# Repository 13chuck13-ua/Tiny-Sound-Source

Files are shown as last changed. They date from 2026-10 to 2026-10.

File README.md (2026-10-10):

# Tiny Sound Source
Tiny Sound Source is an 8-bit LPT DAC compatible with the Covox Speech Thing and Disney Sound Source. It is built around an AVR ATtiny2313 microcontroller and uses a minimal number of additional components.

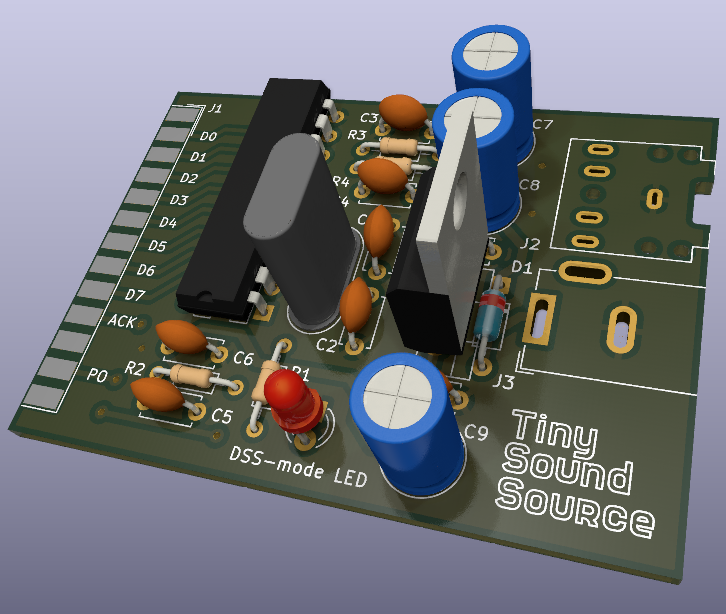
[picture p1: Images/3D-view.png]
Tiny Sound Source


## Key Features:
 - Automatic switching between Covox and DSS modes, with LED indication.
 - Covox mode: flexible sampling rate determined by the host and protection against read errors.
 - DSS mode: doubled output sampling rate (14 kHz) with simple linear interpolation.
 - An additional low-pass filter, automatically enabled by software in DSS mode.
 - Audio output via the built-in PWM at 62.5 kHz.
 - Compatibility with the FTL Sound Adapter.

## Content
 - The **AVR-GCC** directory contains code for the microcontroller.
 - The **KiCad** directory contains the schematic, PCB layout, and Gerber files.

## Tested in the following games:
| Name | Sound | Autodetect  |
| :--- | :---: | :---: |
| Alone in the Dark | 🟢OK | 🟢OK |
| Another World | 🟢OK | ⚪N/A |
| Dungeon Master | 🟢OK | 🟢OK |
| Fast Doom | 🟢OK | ⚪N/A |
| Hocus Pocus | 🟢OK | 🔴Not working|
| King's Quest VI | 🟢OK | 🟢OK |
| Prince of Persia v1.3 | 🟢OK | ⚪N/A |
| Prince of Persia 2 | 🟢OK | ⚪N/A |
| Rocketeer | 🟢OK | ⚪N/A |
| Space Quest V | 🟢OK | ⚪N/A |
| Wolfenstein 3D | 🟢OK | 🟢OK |

**A quick word about Hocus Pocus**.
This game behaves strangely during the DSS auto-detection process. For the device to work correctly, a buffer with TTL input levels needs to be added to the microcontroller's INT0 and INT1 inputs. However, the Tiny Sound Source is, first and foremost, a simple device. I refuse to add a separate chip just for auto-detection in a single game.
To force the use of the Disney Sound Source in Hocus Pocus, use the following command-line switches:
 - **-ss1** for LPT at 0x3BC
 - **-ss2** for LPT at 0x378
 - **-ss3** for LPT at 0x278

## License
The project is distributed under the **GPLv3** license. The license text is in the **GPLv3.txt** file.

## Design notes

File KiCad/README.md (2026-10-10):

# Tiny Sound Source - KiCad files.
Schematic, PCB layout, and Gerber files.

The circuit has been tested and works correctly on:
- **IBM PS/1 model 2121** 80386SX-20MHz
- **CMP MIG-32 laptop** 80286-12MHz

## Schematic
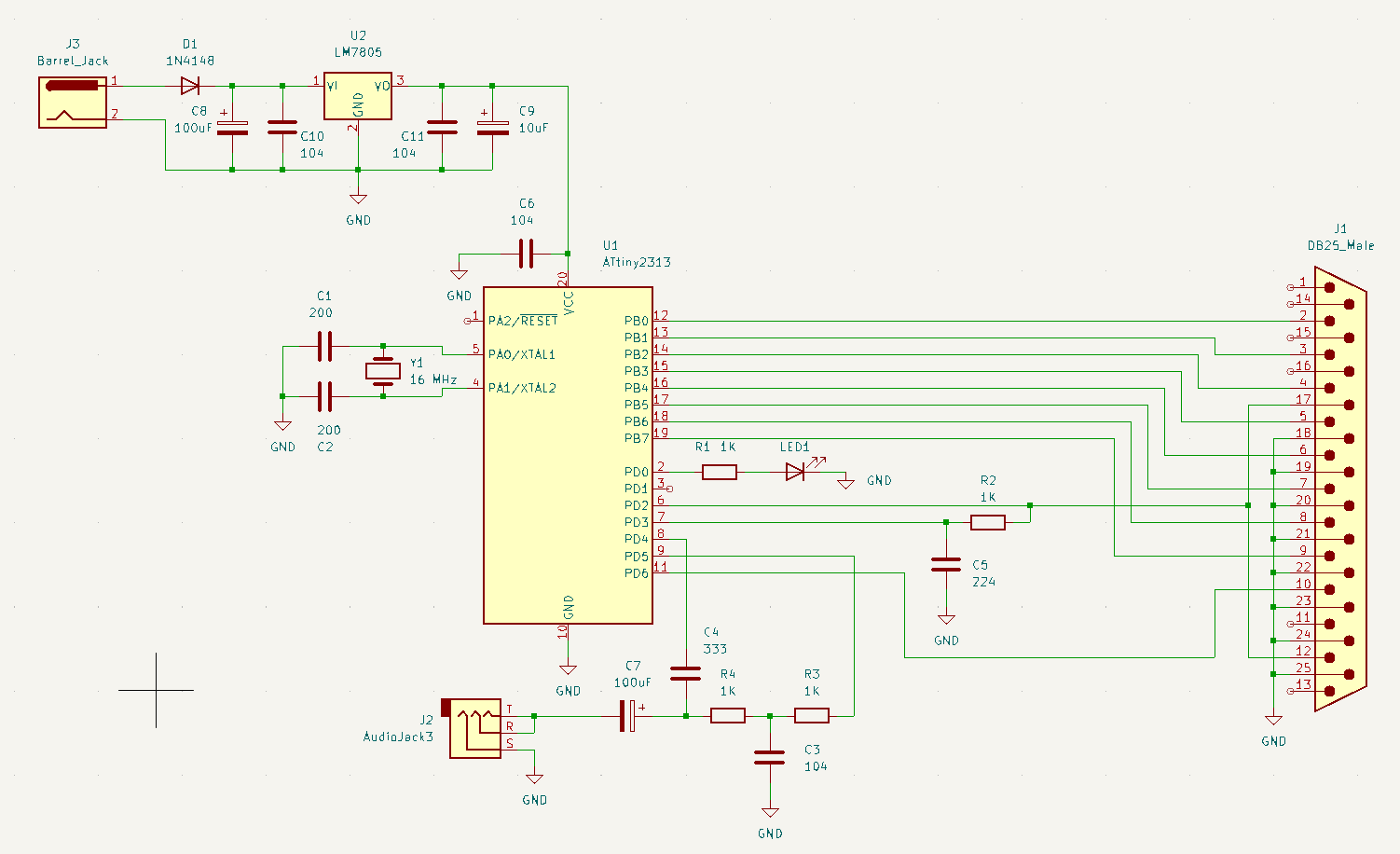
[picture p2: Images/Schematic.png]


 - **R2** та **C5** separate the long SELECT (INT1) signal from the short STROBE (INT0) pulses. Component values may need to be adjusted.
 - **R3** and **C3** are the main PWM output filter.
 - **R4** and **C4** are an additional filter for DSS mode. If you do not need this filter, replace **R4** with a jumper and do not install **C4**.
 - "Compatibility with the FTL Sound Adapter" is simply a jumper wire between pins 12 and 17 of the LPT connector.

## PCB layout
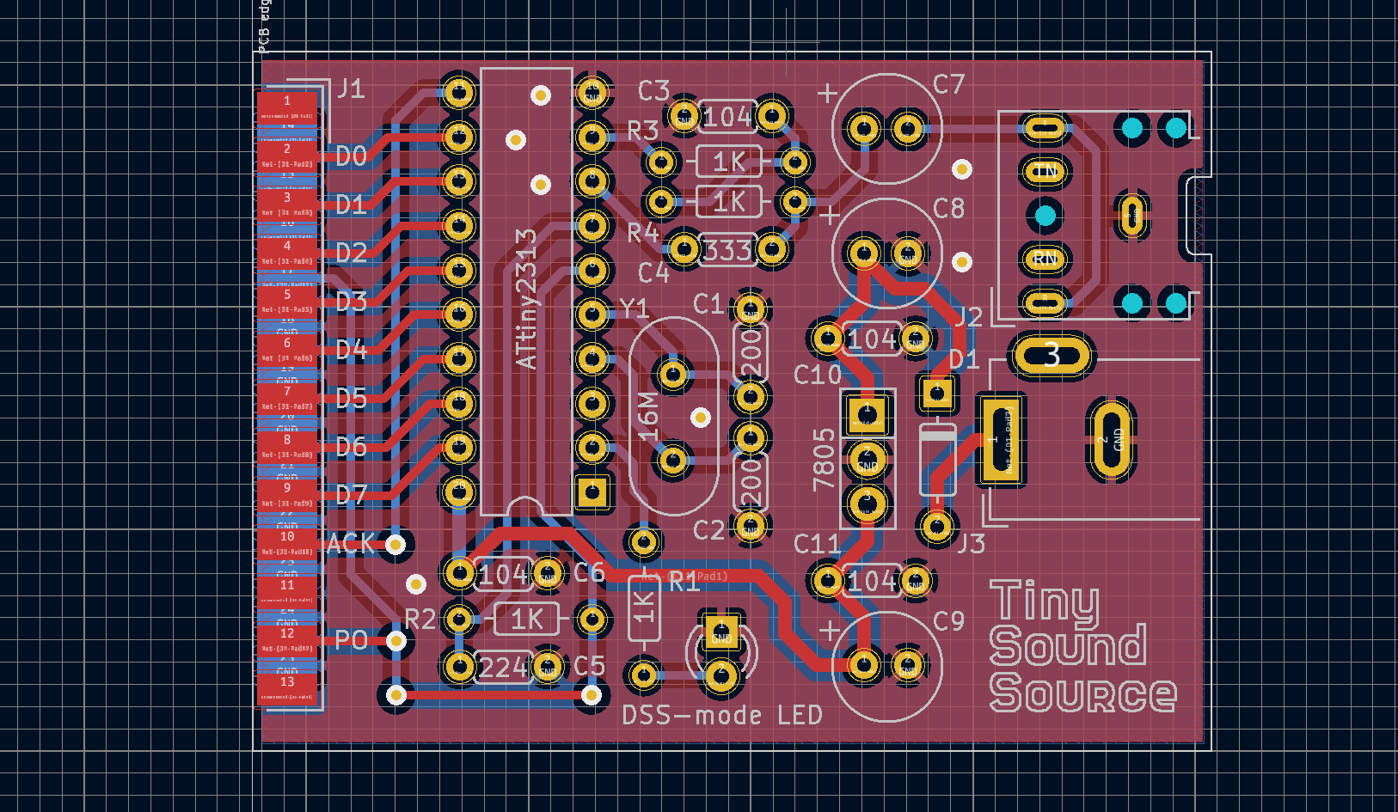
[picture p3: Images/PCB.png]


Ready-to-use Gerber files are located in the Gerber subdirectory.
If you wish to make changes and generate your own Gerber files, I recommend using the User.Drawings layer as F.Silkscreen.

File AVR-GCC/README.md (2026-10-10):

# Tiny Sound Source - GCC code
AVR-GCC firmware for Tiny Sound Source.

## Device:
 - ATtiny2313

## Files:
 - main.c — source code.
 - Makefile — build instructions.
 - tss.hex — compiled firmware image.

## Building:
 - Requires **AVR-GCC** and **GNU Make**.
 - Run make to build the firmware.

## Flashing:
 - Use a compatible AVR programmer and the appropriate flashing utility to write tss.hex to microcontroller.
 - FUSES: LFUSE - **0xDF** HFUSE - **0xD1**

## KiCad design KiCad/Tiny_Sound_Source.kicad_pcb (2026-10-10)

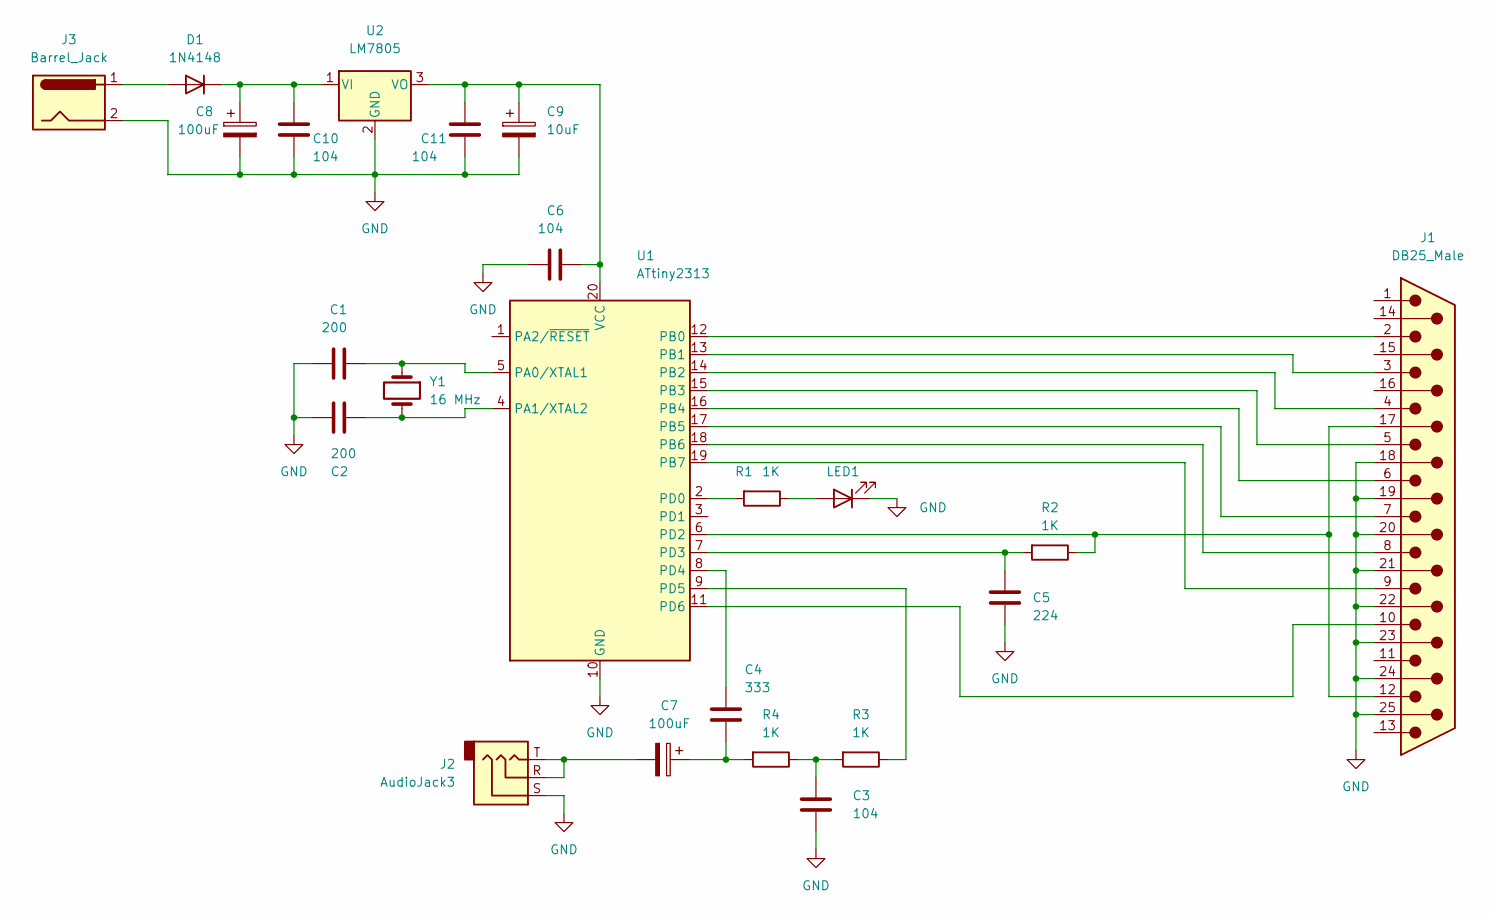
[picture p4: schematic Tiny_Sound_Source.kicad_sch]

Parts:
C1, C2: 200; C_Disc_D4.7mm_W2.5mm_P5.00mm
C3, C6, C10, C11: 104; C_Disc_D4.7mm_W2.5mm_P5.00mm
C4: 333; C_Disc_D4.7mm_W2.5mm_P5.00mm
C5: 224; C_Disc_D4.7mm_W2.5mm_P5.00mm
C7, C8: 100uF; C_Radial_D6.3mm_H11.0mm_P2.50mm
C9: 10uF; C_Radial_D6.3mm_H11.0mm_P2.50mm
D1: 1N4148; D_DO-35_SOD27_P7.62mm_Horizontal
J1: DB25_Male; DSUB-25_Male_EdgeMount_P2.77mm
J2: AudioJack3; Jack_3.5mm_CUI_SJ1-3525N_Horizontal
J3: Barrel_Jack; BarrelJack_GCT_DCJ200-10-A_Horizontal
LED1: DSS-mode LED; LED_D3.0mm
R1, R2, R3, R4: 1K; R_Axial_DIN0204_L3.6mm_D1.6mm_P7.62mm_Horizontal
U1: ATtiny2313; DIP-20_W7.62mm
U2: LM7805; TO-220-3_Vertical
Y1: 16 MHz; Crystal_HC18-U_Vertical

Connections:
GND: C1.1, C2.2, C3.2, C5.2, C6.2, C8.2, C9.2, C10.2, C11.2, J1.18, J1.19, J1.20, J1.21, J1.22, J1.23, J1.24, J1.25, J2.S, J3.2, LED1.1 (K), U1.10 (GND), U2.2 (GND)
unnamed: C1.2, U1.5 (PA0/XTAL1), Y1.1
unnamed: C2.1, U1.4 (PA1/XTAL2), Y1.2
unnamed: C3.1, R3.2, R4.1
unnamed: C4.1, U1.8 (PD4)
unnamed: C4.2, C7.1, R4.2
unnamed: C5.1, R2.2, U1.7 (PD3)
unnamed: C7.2, J2.R, J2.T
unnamed: C8.1, C10.1, D1.1 (K), U2.1 (VI)
unnamed: C6.1, C9.1, C11.1, U1.20 (VCC), U2.3 (VO)
unnamed: D1.2 (A), J3.1
unnamed: J1.2, U1.12 (PB0)
unnamed: J1.3, U1.13 (PB1)
unnamed: J1.4, U1.14 (PB2)
unnamed: J1.5, U1.15 (PB3)
unnamed: J1.6, U1.16 (PB4)
unnamed: J1.7, U1.17 (PB5)
unnamed: J1.8, U1.18 (PB6)
unnamed: J1.9, U1.19 (PB7)
unnamed: J1.10, U1.11 (PD6)
unnamed: J1.12, J1.17, R2.1, U1.6 (PD2)
unnamed: LED1.2 (A), R1.1
unnamed: R1.2, U1.2 (PD0)
unnamed: R3.1, U1.9 (PD5)

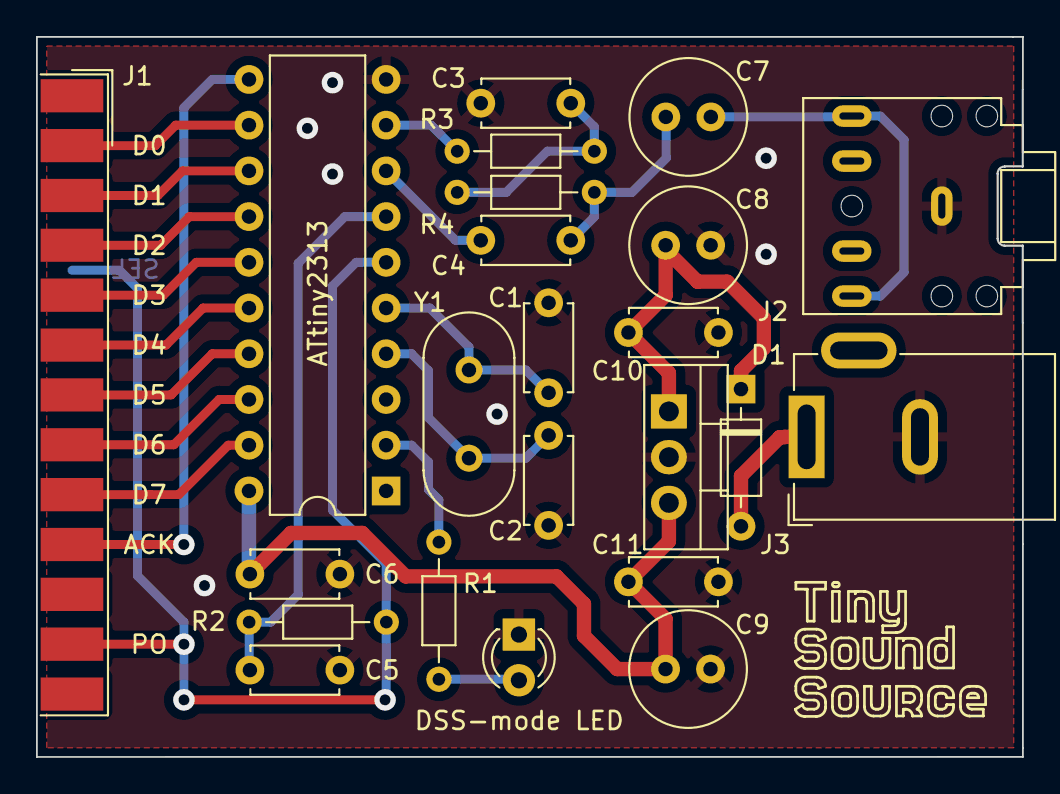
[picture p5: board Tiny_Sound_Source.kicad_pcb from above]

Board: 2 copper layers, 54.8 x 40.0 mm, 23 parts (0 on the bottom side), 24 nets.

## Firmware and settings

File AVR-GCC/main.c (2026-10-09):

/* ============================================================================
 *   _______             ____                  __  ____
 *  /_  __(_)__  __ __  / __/__  __ _____  ___/ / / __/__  __ _____________
 *   / / / / _ \/ // / _\ \/ _ \/ // / _ \/ _  / _\ \/ _ \/ // / __/ __/ -_)
 *  /_/ /_/_//_/\_, / /___/\___/\_,_/_//_/\_,_/ /___/\___/\_,_/_/  \__/\__/
 *             /___/
 *  Tiny Sound Source
 *  Disney Sound Source replica project with Covox Speech Thing compatible mode
 *
 *  ver: 1.0
 *  author: 13chuck13
 *  date: 09.10.2026
 * ----------------------------------------------------------------------------
 *  ATtiny-2313 pinout:
 *                  -----
 *                -|o    |- VCC (+5V)
 *      (LED) PD0 -|     |- PB7 -
 *                -|     |- PB6  |
 *          XTAL2 -|     |- PB5  |
 *          XTAL1 -|     |- PB4  |- (LPT data)
 *  (STROBE) INT0 -|     |- PB3  |
 *  (SELECT) INT1 -|     |- PB2  |
 *  (DSS cap) PD4 -|     |- PB1  |
 *     (PWM) OC0B -|     |- PB0 -
 *            GND -|     |- PD6 (FIFO-FULL)
 *                  -----
 *
 *  Description:
 *    PB0-PB7:      8 bit data input from LPT
 *    OC0B:         Sound output (need external RC filter)
 *    INT0:         STROBE input from LPT
 *    INT1:         SELECT input from RC low-pass filter
 *    PD0:          Mode-LED
 *    PD4:          Additional capacitor for low-pass filtering in DSS mode
 *    PD6:          FIFO-FULL output
 *    XTAL1/XTAL2:  External crystal oscillator (16 MHz)
 *
 *
 *  Clock:   external oscillator 16 MHz
 *
 *  Fuses:
 *           LFUSE = 0xDF
 *           HFUSE = 0xD1
 *           EFUSE = 0xFF
 *           LOCK = 0xFF
 *
   ---------------------------------------------------------------------------- */


#include <avr/io.h>
#include <avr/interrupt.h>


typedef unsigned char byte;


#define F_CPU 16000000UL
#define FIFO_SIZE  32               /* ОБОВ'ЯЗКОВО двійка в ступені */
#define FIFO_MASK  (FIFO_SIZE - 1)
#define DAC_MID 128                 /* значення idle-state для ШІМ */
#define MODE_COVOX 0
#define MODE_DSS 1


volatile byte fifo[FIFO_SIZE];
volatile byte index_wr = 0;
volatile byte index_rd = 0;
volatile byte fifo_counter = 0;
volatile byte mode = MODE_COVOX;
volatile byte value_prev = DAC_MID;


void init(void);
inline void fifo_push(byte data);
inline byte fifo_pop(void);


/* ------------------------------------------------------- */


ISR(INT0_vect)  /* запис вхідних даних у DSS FIFO */
{
    byte data;

    data = PINB;
    fifo_push(data);
}


ISR(INT1_vect)  /* зміна режиму Covox/DSS */
{
    if(mode == MODE_COVOX)
    {
        mode = MODE_DSS;
        MCUCR &= ~(1 << ISC10);     /* INT1 по задньому фронту сигналу */
        MCUCR |=  (1 << ISC11);
        index_wr = 0;               /* скидаємо значення FIFO */
        index_rd = 0;
        fifo_counter = 0;
        PORTD &= ~(1 << PD6);       /* FIFO-FULL off */
        TCNT1 = 0;                  /* скидаємо таймер */
        TIMSK |= (1 << OCIE1A);     /* вмикаємо Timer1 */
        GIMSK |= (1 << INT0);       /* вмикаємо переривання по STROBE */
        PORTD &= ~(1 << PD0);       /* вмикаємо додатковий low-pass на виході PWM */
        DDRD |= (1 << PD4);
        PORTD |= (1 << PD0);        /* LED on */
    }
    else    /* mode == MODE_DSS */
    {
        mode = MODE_COVOX;
        MCUCR |= (1 << ISC11) | (1 << ISC10);   /* INT1 по передньому фронту сигналу */
        TIMSK &= ~(1 << OCIE1A);                /* вимикаємо Timer1 */
        PORTD &= ~(1 << PD6);                   /* FIFO-FULL off */
        GIMSK &= ~(1 << INT0);                  /* вимикаємо переривання по STROBE */
        DDRD &= ~(1 << PD4);                    /* вимикаємо додатковий low-pass на виході PWM */
        PORTD &= ~(1 << PD0);                   /* LED off */
    }
}


ISR(TIMER1_COMPA_vect)  /* відтворення звуку DSS */
{
    byte value;

    value = fifo_pop();
    if(value != value_prev)
    {
        OCR0B = value;      /* пишемо чергове значення в PWM */
        value_prev = value;
    }
}


int main(void)
{
    byte sample_1;
    byte sample_2;

    init();
    sei();  /* глобальний дозвіл переривань */

    for (;;)
    {
        while(mode == MODE_COVOX)
        {
            sample_1 = PINB;
            sample_2 = PINB;
            while(sample_1 == sample_2)
            {
                sample_2 = PINB;
            }
            __asm__ __volatile__("nop");    /* чекаємо стабільного стану на шині */
            __asm__ __volatile__("nop");
            __asm__ __volatile__("nop");
            __asm__ __volatile__("nop");
            __asm__ __volatile__("nop");
            OCR0B = PINB;
        }
    }
}


void init(void)
{
    /* GPIO */
    DDRB = 0x00;            /* всі піни PB як вхід */
    DDRD &= ~(1 << PD2);    /* PD2(INT0) як вхід */
    DDRD &= ~(1 << PD3);    /* PD3(INT1) як вхід */
    DDRD &= ~(1 << PD4);    /* PD4(DSS cap) як вхід */
    DDRD |= (1 << PD0);     /* PD0(MODE-LED) як вихід */
    DDRD |= (1 << PD5);     /* PD5(OC0B/PWM) як вихід */
    DDRD |= (1 << PD6);     /* PD6(FIFO-FULL) як вихід */
    PORTD &= ~(1 << PD0);   /* PD0(MODE-LED) = OFF */
    PORTD &= ~(1 << PD6);   /* PD6(FIFO-FULL) = LOW */
    PORTB = 0xFF;           /* увімкнути підтягуючі резистори на PB */
    PORTD |= (1 << PD2);    /* увімкнути підтягуючий резистор на INT0 */
    PORTD |= (1 << PD3);    /* увімкнути підтягуючий резистор на INT1 */

    /* INT */
    MCUCR &= ~(1 << ISC00);                 /* INT0 по задньому фронту сигналу */
    MCUCR |=  (1 << ISC01);
    MCUCR |= (1 << ISC11) | (1 << ISC10);   /* INT1 по передньому фронту сигналу */
    GIMSK &= ~(1 << INT0);                  /* заборона зовнішнього переривання INT0 */
    GIMSK |= (1 << INT1);                   /* дозвіл зовнішнього переривання INT1 */

    /* Timer */
    TCCR1A = 0;
    TCCR1B = (1 << WGM12) | (1 << CS10);
    /* Wingardium leviosa! (чарівна константа в коді :) */
    OCR1A = 1142;                           /* 14 KHz */
    TIMSK &= ~(1 << OCIE1A);                /* вимикаємо Timer1 */

    /* PWM */
    TCCR0A =                /* 62 KHz 256 відліків */
        (1 << WGM00) |
        (1 << WGM01) |
        (1 << COM0B1);
    TCCR0B =
        (1 << CS00);
    OCR0B = DAC_MID;
}


inline void fifo_push(byte data)
{
    if (fifo_counter > FIFO_SIZE - 2)   /* нема двох вільних байтів */
    {
        /* Ми не мали тут опинитись, але ось ми тут */
        return;
    }

    if (fifo_counter == 0)
    {
        fifo[index_wr] = (DAC_MID + data) / 2;
    }
    else
    {
        fifo[index_wr] = (fifo[(index_wr - 1) & FIFO_MASK] + data) / 2;
    }

    fifo[(index_wr + 1) & FIFO_MASK] = data;

    index_wr = (index_wr + 2) & FIFO_MASK;
    fifo_counter += 2;

    if (fifo_counter > FIFO_SIZE - 2)
    {
        PORTD |= (1 << PD6);   /* високий рвіень на FIFO-FULL */
    }
}


inline byte fifo_pop(void)
{
    byte data;

    if (fifo_counter == 0)  /* буфер порожній */
    {
        return DAC_MID;
    }

    data = fifo[index_rd];
    index_rd = (index_rd + 1) & FIFO_MASK;
    fifo_counter--;

    if(fifo_counter == (FIFO_SIZE - 2))
    {
        PORTD &= ~(1 << PD6);    /* низький рівень на FIFO-FULL */
    }

    return data;
}
